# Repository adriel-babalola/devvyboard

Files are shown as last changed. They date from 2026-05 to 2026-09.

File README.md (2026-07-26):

## What is it ?
The rp2040 dev board is  a micro-controller unit that consist of the rp2040 micro processor, the 16Mbit SPI NOR Flash, a crystal oscillator that synchronizes communication in the board between the USB abd rp2040, a voltage regulator, reset and boot switch.

##  Why i built it ?
I built devvy, to understand in depth what exactly goes on in a micro-controller, and how exactly do teh components interact, and now i understand what goes on behind the scenes plus i made a rp2040 dev board.

## Assembly Instructions
1. PCB Assembly: All 0402/0603 SMD components soldered by PCBWay PCBA
2. Manual Soldering: 
   - pin Headers 
3. Testing: Apply 5V via USB-C, probe 3V3 rail with multimeter (should show 3.3V), but I tested it with an LED on the 3v3 and it works fine, will proceed to much complex projects later on.
4. Firmware: Flash using RP2040 USB bootloader (hold BOOT, press RESET, drag `.uf2` to `RPI-RP2` drive)

## CAD & Design Files
- PCB Design : KiCAD – see `devvyboard/` folder
- Gerbers: `devvyboard_gebers.zip`
- 3D CAD: `.step` files in `devvyboard_3d_step/` folder

## The Final Soldered Borad

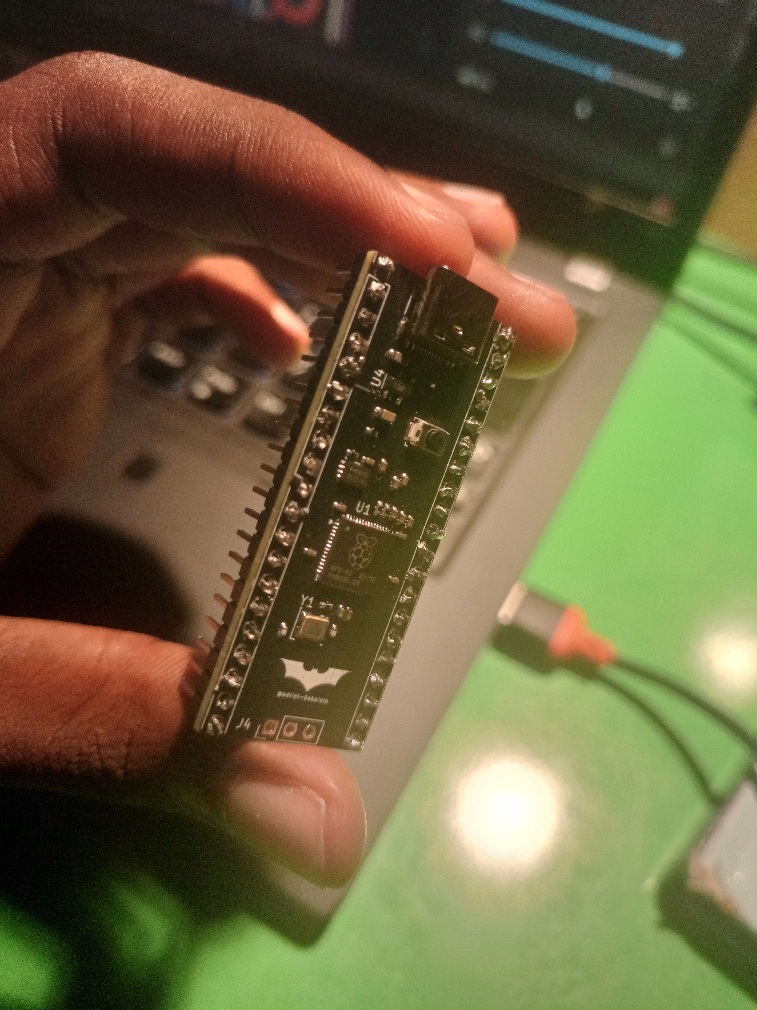
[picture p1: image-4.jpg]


## The CAD View 
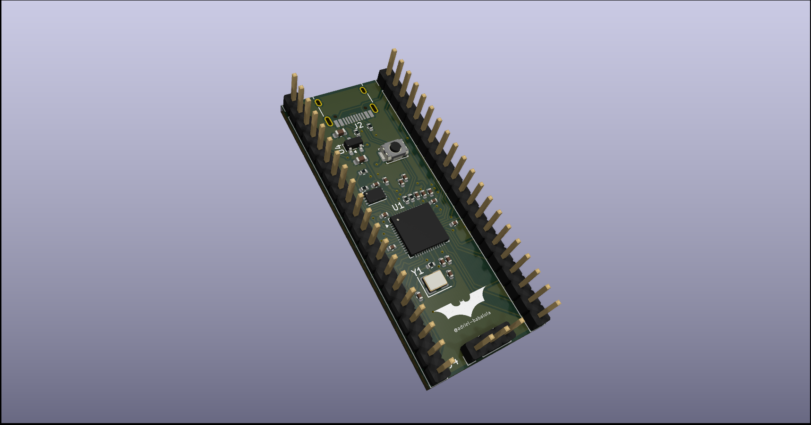
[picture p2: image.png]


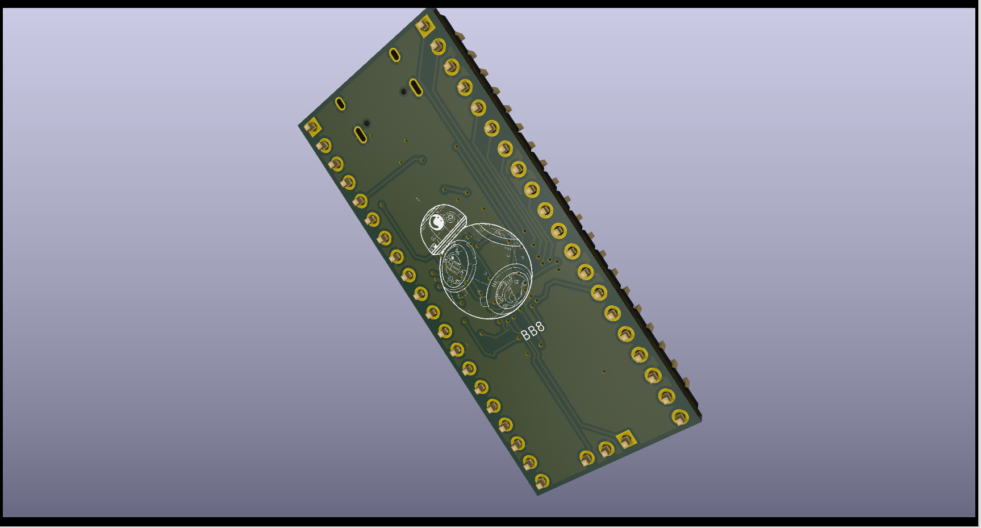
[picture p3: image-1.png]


## The Schematics 
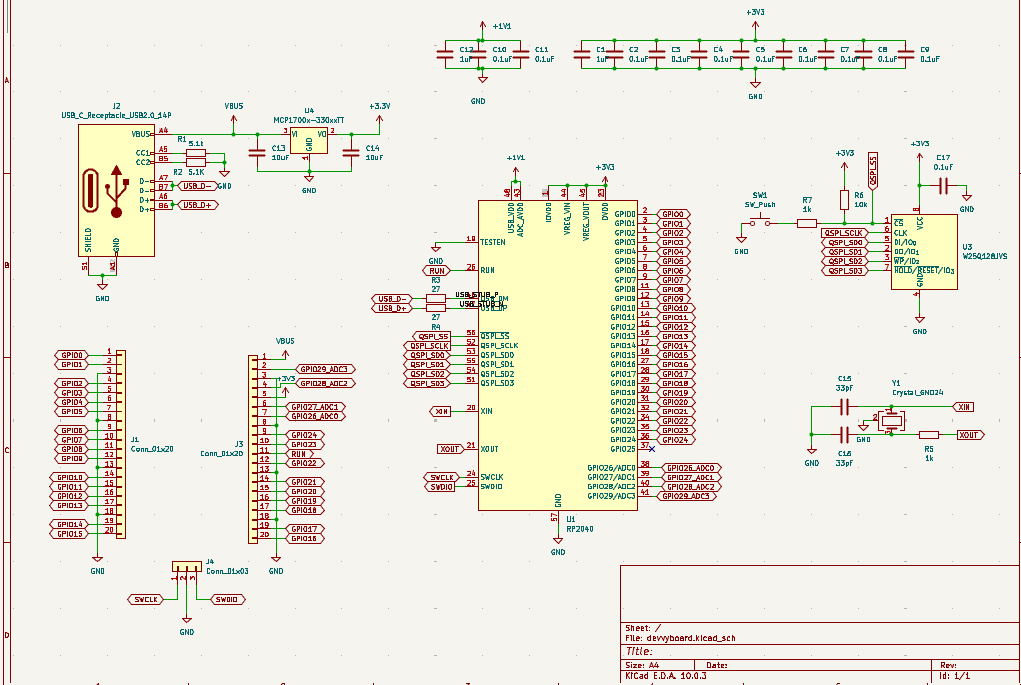
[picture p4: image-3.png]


## The Final Routed PCB
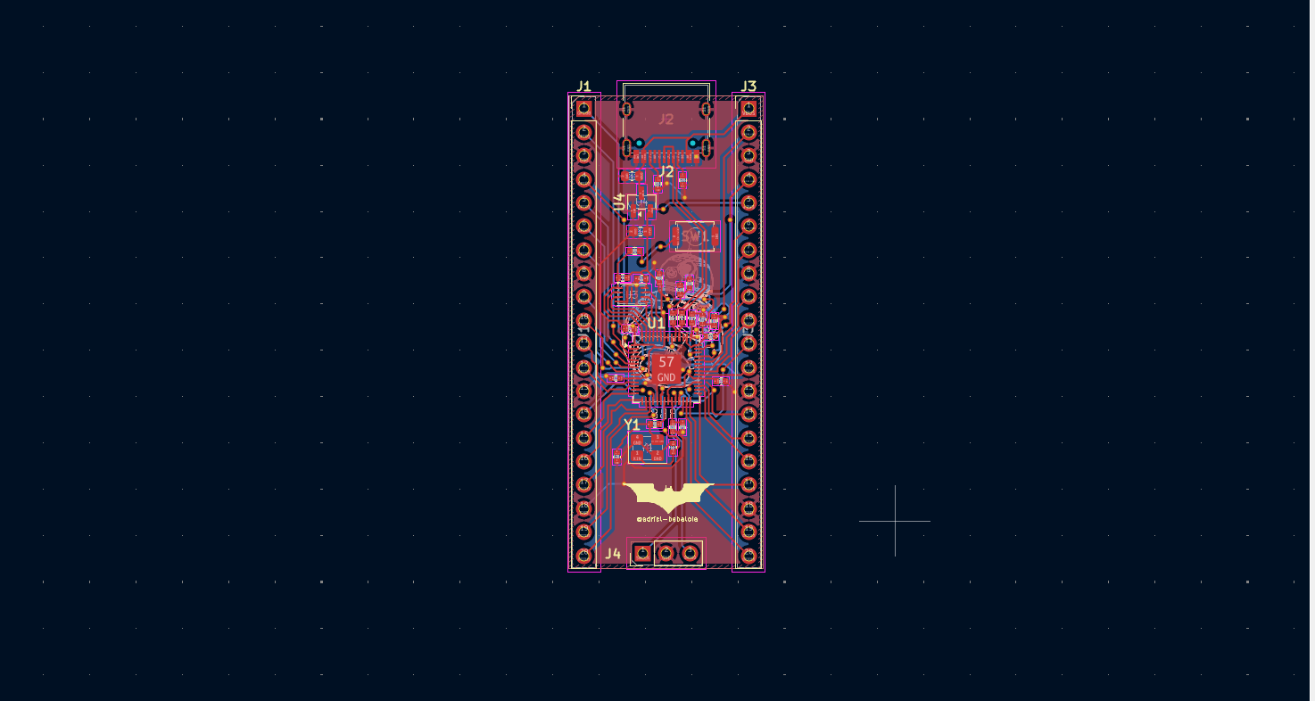
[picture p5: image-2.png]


## Bill of Materials

| Name | Purpose | Qty | Total (USD) | Link | Distributor |
|---|---|-----|---|---|---|
|Connectors | For external connections | 10 | $1.5 | [Connectors](https://www.aliexpress.com/item/1005007385580884.html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) | Aliexpress
|Soldering Iron | To Solder | 1 | $5.3 | [Soldering Iron](https://www.aliexpress.com/item/1005009943749655.html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) | Aliexpress
| RP2040 | Dual-core ARM Cortex-M0+ microcontroller — the brain of the board | 1 | $0.69 | [LCSC C2040](https://www.lcsc.com/product-detail/C2040.html) | JLCPCB |
| W25Q16JVUXIQ Flash | 16Mbit SPI NOR Flash — stores firmware and data | 1 | $0.18 | [LCSC C2843335](https://www.lcsc.com/product-detail/C2843335.html) | JLCPCB |
| 12MHz Crystal (X322512MSB4SI) | Crystal oscillator — synchronises USB and RP2040 communication | 1 | $0.04 | [LCSC C9002](https://www.lcsc.com/product-detail/C9002.html) | JLCPCB |
| TYPE-C-31-M-12 USB-C Receptacle | USB-C port — data transfer and board power input | 1 | $0.09 | [LCSC C165948](https://www.lcsc.com/product-detail/C165948.html) | JLCPCB |
| MCP1700T-3302E/TT LDO | 3.3V voltage regulator — powers all 3.3V components | 1 | $0.18 | [LCSC C39051](https://www.lcsc.com/product-detail/C39051.html) | JLCPCB |
| Alps SKRKAHE020 Tactile Switch | Reset/boot switch — resets or boot-selects the RP2040 | 1 | $0.08 | [LCSC C202388](https://www.lcsc.com/product-detail/C202388.html) | LCSC |
| 100nF 0402 Capacitor x11 | Decoupling — filters noise on power rails | 11 | $0.02 | [LCSC C1525](https://www.lcsc.com/product-detail/C1525.html) | JLCPCB |
| 1uF 0402 Capacitor x2 | Bulk decoupling — stabilises power at RP2040 and USB | 2 | $0.02 | [LCSC C52923](https://www.lcsc.com/product-detail/C52923.html) | JLCPCB |
| 10uF 0603 Capacitor x2 | Input/output bulk capacitance — LDO stability | 2 | $0.02 | [LCSC C19702](https://www.lcsc.com/product-detail/C19702.html) | JLCPCB |
| 33pF 0402 Capacitor x2 | Crystal load capacitors — correct oscillator loading | 2 | $0.01 | [LCSC C1557](https://www.lcsc.com/product-detail/C1557.html) | JLCPCB |
| 5.1k 0402 Resistor x2 | USB-C CC resistors — identifies board as USB device to host | 2 | $0.01 | [LCSC C25905](https://www.lcsc.com/product-detail/C25905.html) | JLCPCB |
| 27R 0402 Resistor x2 | USB D+/D- series resistors — USB signal integrity | 2 | $0.01 | [LCSC C352446](https://www.lcsc.com/product-detail/C352446.html) | JLCPCB |
| 1k 0402 Resistor x2 | Current limiting / pull resistors | 2 | $0.01 | [LCSC C11702](https://www.lcsc.com/product-detail/C11702.html) | JLCPCB |
| 10k 0402 Resistor | Pull-up/pull-down bias resistor | 1 | $0.01 | [LCSC C25744](https://www.lcsc.com/product-detail/C25744.html) | JLCPCB |
| PCB Fabrication (devvyboard_Y4) | 2-layer PCB — the board itself | 5 | $2.00 | — | JLCPCB |
| PCBA SMT Assembly | SMT assembly of all SMD components | 2 | $80.06 | — | JLCPCB |
| Shipping PCB | Economical Global Direct Line 14-19 business days | - | $13.10 | — | JLCPCB |
|Shipping Aliexpress | - | - | $5.23 | - | Aliexpress
| **TOTAL** | | | **$107.36** | | |

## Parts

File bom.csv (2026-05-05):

Name | Purpose | Quantity | Total (USD) | Link | Distributor
RP2040 | Dual-core ARM Cortex-M0+ microcontroller - the brain of the board | 1 | $0.69 | https://www.lcsc.com/product-detail/C2040.html | JLCPCB (C2040)
W25Q16JVUXIQ Flash | 16Mbit SPI NOR Flash - stores firmware and data | 1 | $0.18 | https://www.lcsc.com/product-detail/C2843335.html | JLCPCB (C2843335)
12MHz Crystal (X322512MSB4SI) | Crystal oscillator - synchronises USB and RP2040 communication | 1 | $0.04 | https://www.lcsc.com/product-detail/C9002.html | JLCPCB (C9002)
TYPE-C-31-M-12 USB-C Receptacle | USB-C port - data transfer and board power input | 1 | $0.09 | https://www.lcsc.com/product-detail/C165948.html | JLCPCB (C165948)
MCP1700T-3302E/TT LDO | 3.3V voltage regulator - powers all 3.3V components | 1 | $0.18 | https://www.lcsc.com/product-detail/C39051.html | JLCPCB (C39051)
Alps SKRKAHE020 Tactile Switch | Reset/boot switch - resets or boot-selects the RP2040 | 1 | $0.08 | https://www.lcsc.com/product-detail/C202388.html | LCSC (C202388)
1x20 Pin Headers (x2) | GPIO breakout - exposes all RP2040 pins for external projects | 10 | $1.50 | https://www.aliexpress.com | AliExpress
Soldering Iron | To solder the connectors and switch | 1 | $5.30 | https://www.aliexpress.com | AliExpress
100nF 0402 Capacitor (x11) | Decoupling - filters noise on power rails | 11 | $0.02 | https://www.lcsc.com/product-detail/C1525.html | JLCPCB (C1525)
1uF 0402 Capacitor (x2) | Bulk decoupling - stabilises power at RP2040 and USB | 2 | $0.02 | https://www.lcsc.com/product-detail/C52923.html | JLCPCB (C52923)
10uF 0603 Capacitor (x2) | Input/output bulk capacitance - LDO stability | 2 | $0.02 | https://www.lcsc.com/product-detail/C19702.html | JLCPCB (C19702)
33pF 0402 Capacitor (x2) | Crystal load capacitors - correct oscillator loading | 2 | $0.01 | https://www.lcsc.com/product-detail/C1557.html | JLCPCB (C1557)
5.1k 0402 Resistor (x2) | USB-C CC resistors - identifies board as USB device to host | 2 | $0.01 | https://www.lcsc.com/product-detail/C25905.html | JLCPCB (C25905)
27R 0402 Resistor (x2) | USB D+/D- series resistors - USB signal integrity | 2 | $0.01 | https://www.lcsc.com/product-detail/C352446.html | JLCPCB (C352446)
1k 0402 Resistor (x2) | Current limiting / pull resistors | 2 | $0.01 | https://www.lcsc.com/product-detail/C11702.html | JLCPCB (C11702)
10k 0402 Resistor | Pull-up/pull-down bias resistor | 1 | $0.01 | https://www.lcsc.com/product-detail/C25744.html | JLCPCB (C25744)
PCB Fabrication (devvyboard_Y4) | 2-layer PCB - the board itself | 5 | $2.00 | - | JLCPCB
PCBA Assembly | SMT assembly of all SMD components | 2 | $80.06 | - | JLCPCB
Shipping | Delivery | 1 | $18.50 | - | JLCPCB + AliExpress
TOTAL |  |  |  | $107.36

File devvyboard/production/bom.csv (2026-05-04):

Designator | Footprint | Quantity | Value | LCSC Part #
C1, C12 | 0402 | 2 | 1uF
C10, C11, C17, C2, C3, C4, C5, C6, C7, C8, C9 | 0402 | 11 | 0.1uF
C13, C14 | 0603 | 2 | 10uF
C15, C16 | 0402 | 2 | 33pF
J1, J3 | PinHeader_1x20_P2.54mm_Vertical | 2 | Conn_01x20
J2 | USB_C_Receptacle_HRO_TYPE-C-31-M-12 | 1 | USB_C_Receptacle_USB2.0_14P
J4 | PinHeader_1x03_P2.54mm_Vertical | 1 | Conn_01x03
R1, R2 | 0402 | 2 | 5.1k
R3, R4 | 0402 | 2 | 27
R5, R7 | 0402 | 2 | 1k
R6 | 0402 | 1 | 10k
SW1 | SW_Push_SPST_NO_Alps_SKRK | 1 | SW_Push
U1 | QFN-56-1EP_7x7mm_P0.4mm_EP3.2x3.2mm | 1 | RP2040
U3 | Winbond_USON-8-1EP_3x2mm_P0.5mm_EP0.2x1.6mm | 1 | W25Q16JVUXIQ
U4 | SOT-23 | 1 | MCP1700x-330xxTT
Y1 | Crystal_SMD_3225-4Pin_3.2x2.5mm | 1 | Crystal_GND24

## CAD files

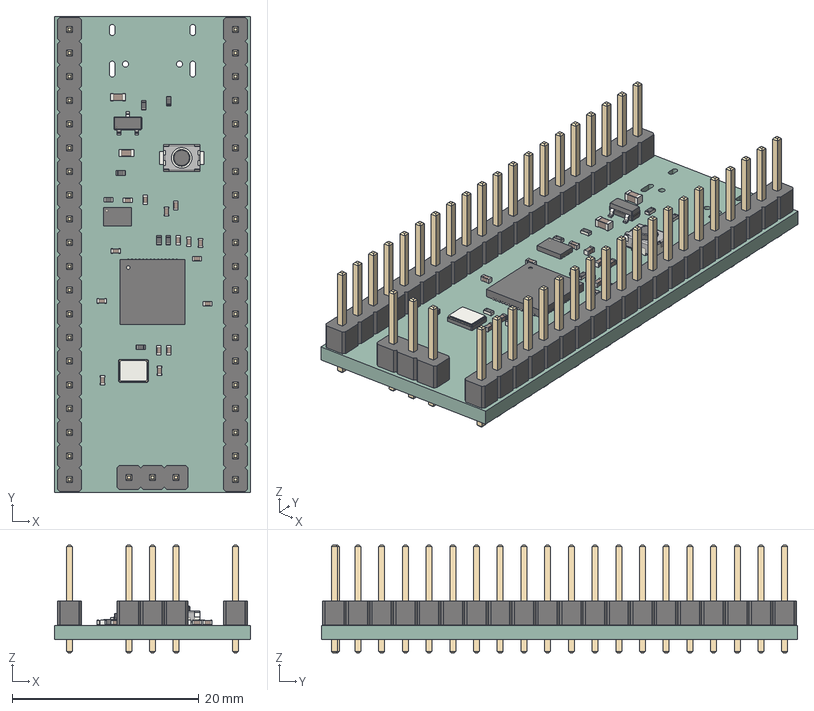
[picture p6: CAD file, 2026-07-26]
devvyboard 3d step/.step
21.0 x 51.0 x 11.5 mm
C_0402_1005Metric x 15
R_0402_1005Metric x 7
C_0603_1608Metric x 2
SOT-23
SW_Push_SPST_NO_Alps_SKRK
Crystal_SMD_3225-4Pin_3.2x2.5mm
QFN-56-1EP_7x7mm_P0.4mm_EP3.2x3.2mm
PinHeader_1x03_P254mm_Vertical
PinHeader_1x20_P254mm_Vertical x 2
Winbond_USON-8-1EP_3x2mm_P0.5mm_EP0.2x1.6mm
devvyboard_PCB

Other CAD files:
devvyboard_3d_step/devvyboard.step
devvyboard_3d_step/devvyboard.f3z

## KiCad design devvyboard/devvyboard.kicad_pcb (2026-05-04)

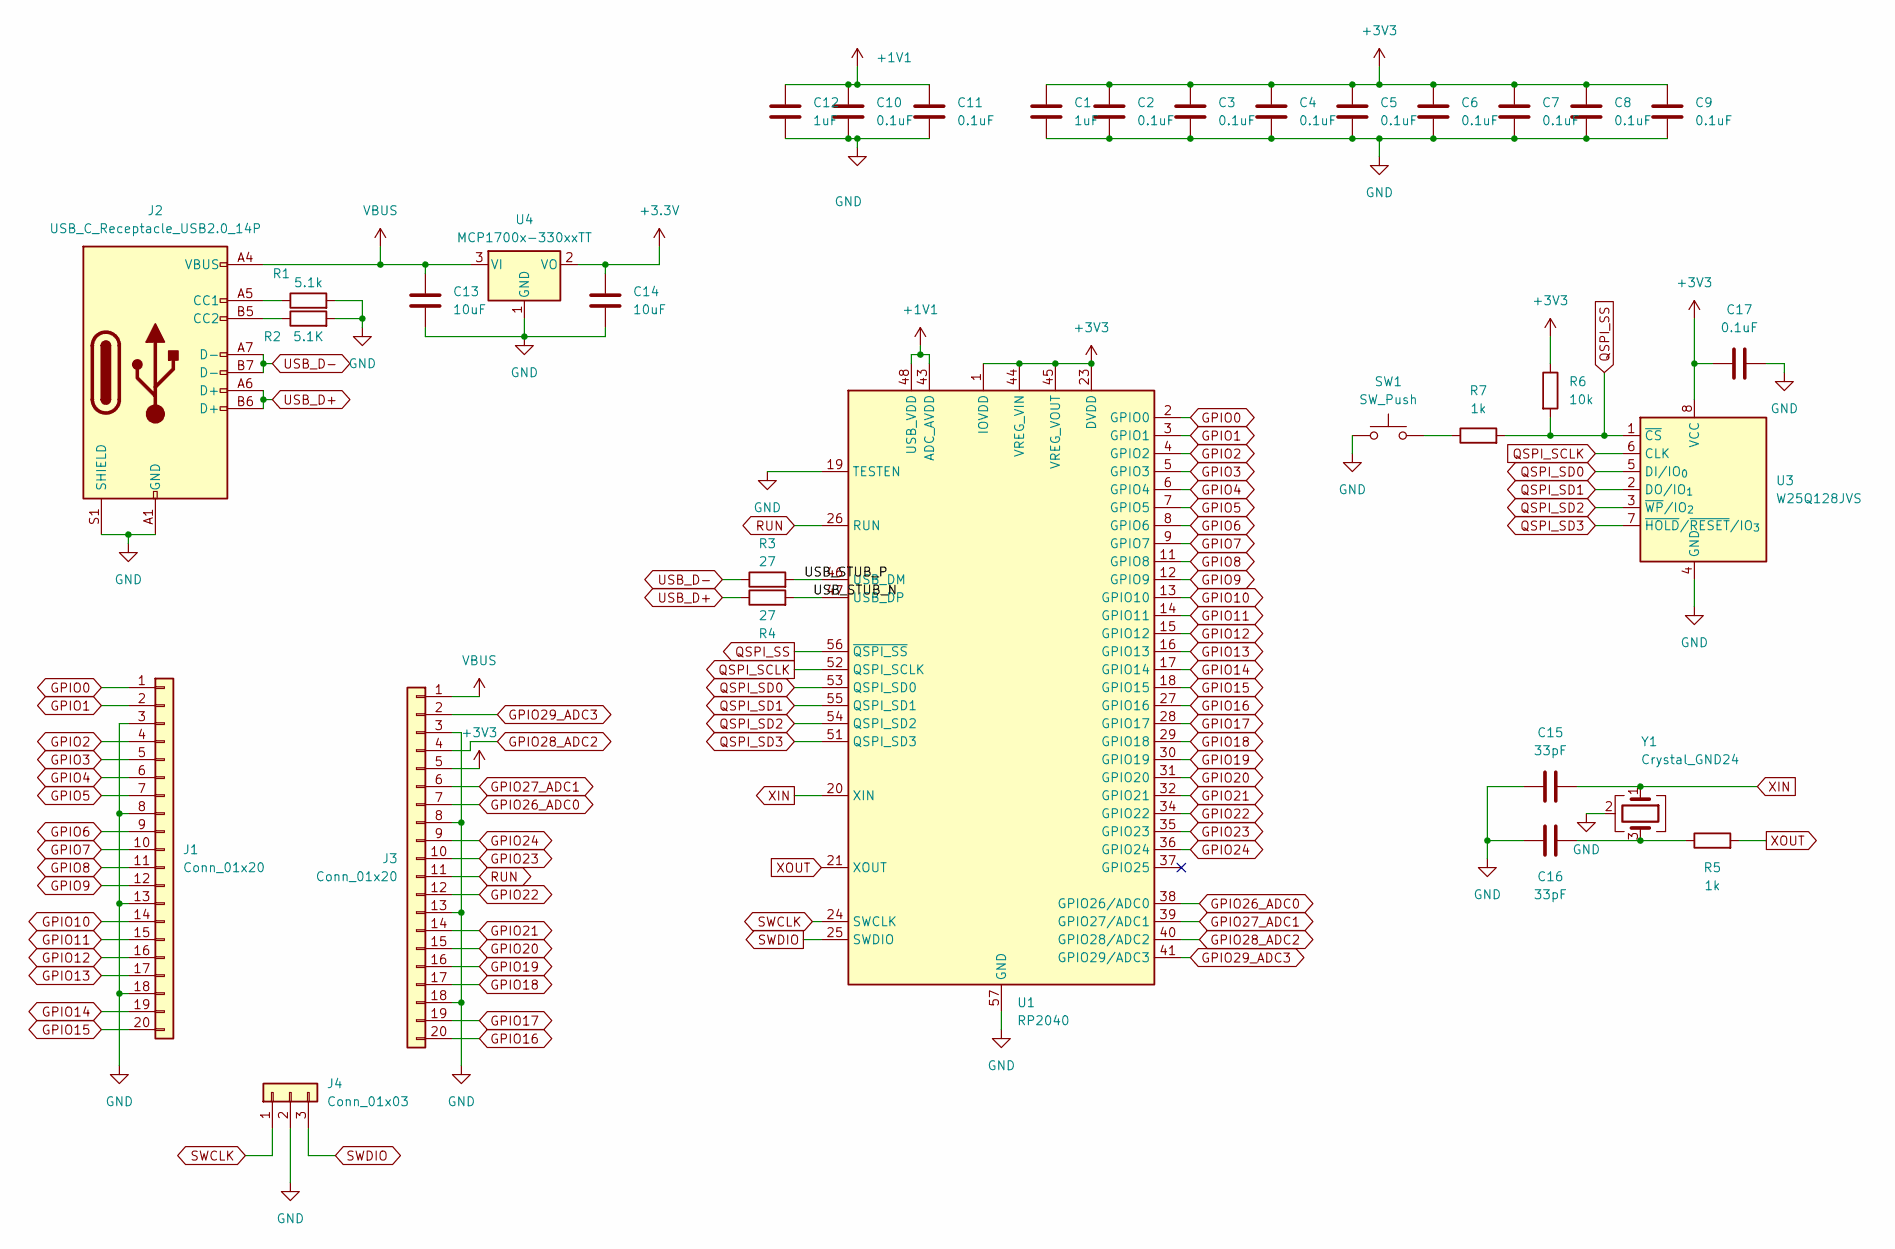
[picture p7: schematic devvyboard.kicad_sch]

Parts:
C1, C12: 1uF; C_0402_1005Metric
C2, C3, C4, C5, C6, C7, C8, C9, C10, C11, C17: 0.1uF; C_0402_1005Metric
C13, C14: 10uF; C_0603_1608Metric
C15, C16: 33pF; C_0402_1005Metric
J1, J3: Conn_01x20; PinHeader_1x20_P2.54mm_Vertical
J2: USB_C_Receptacle_USB2.0_14P; USB_C_Receptacle_HRO_TYPE-C-31-M-12
J4: Conn_01x03; PinHeader_1x03_P2.54mm_Vertical
R1: 5.1k; R_0402_1005Metric
R2: 5.1K; R_0402_1005Metric
R3, R4: 27; R_0402_1005Metric
R5, R7: 1k; R_0402_1005Metric
R6: 10k; R_0402_1005Metric
SW1: SW_Push; SW_Push_SPST_NO_Alps_SKRK
U1: RP2040; QFN-56-1EP_7x7mm_P0.4mm_EP3.2x3.2mm
U3: W25Q128JVS; Winbond_USON-8-1EP_3x2mm_P0.5mm_EP0.2x1.6mm
U4: MCP1700x-330xxTT; SOT-23
Y1: Crystal_GND24; Crystal_SMD_3225-4Pin_3.2x2.5mm

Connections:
+1V1: C10.1, C11.1, C12.1, U1.43 (ADC_AVDD), U1.48 (USB_VDD)
/USB_STUB_N: R4.2, U1.47 (USB_DP)
/USB_STUB_P: R3.2, U1.46 (USB_DM)
GND: C1.2, C2.2, C3.2, C4.2, C5.2, C6.2, C7.2, C8.2, C9.2, C10.2, C11.2, C12.2, C13.2, C14.2, C15.1, C16.1, C17.1, J1.3, J1.8, J1.13, J1.18, J2.A1 (GND), J2.A12 (GND), J2.B1 (GND), J2.B12 (GND), J2.S1 (SHIELD), J3.3, J3.8, J3.13, J3.18, J4.2, R1.2, R2.2, SW1.1, U1.19 (TESTEN), U1.57 (GND), U3.4 (GND), U4.1 (GND), Y1.2 (G), Y1.4 (G)
GPIO0: J1.1, U1.2 (GPIO0)
GPIO1: J1.2, U1.3 (GPIO1)
GPIO2: J1.4, U1.4 (GPIO2)
GPIO3: J1.5, U1.5 (GPIO3)
GPIO4: J1.6, U1.6 (GPIO4)
GPIO5: J1.7, U1.7 (GPIO5)
GPIO6: J1.9, U1.8 (GPIO6)
GPIO7: J1.10, U1.9 (GPIO7)
GPIO8: J1.11, U1.11 (GPIO8)
GPIO9: J1.12, U1.12 (GPIO9)
GPIO10: J1.14, U1.13 (GPIO10)
GPIO11: J1.15, U1.14 (GPIO11)
GPIO12: J1.16, U1.15 (GPIO12)
GPIO13: J1.17, U1.16 (GPIO13)
GPIO14: J1.19, U1.17 (GPIO14)
GPIO15: J1.20, U1.18 (GPIO15)
GPIO16: J3.20, U1.27 (GPIO16)
GPIO17: J3.19, U1.28 (GPIO17)
GPIO18: J3.17, U1.29 (GPIO18)
GPIO19: J3.16, U1.30 (GPIO19)
GPIO20: J3.15, U1.31 (GPIO20)
GPIO21: J3.14, U1.32 (GPIO21)
GPIO22: J3.12, U1.34 (GPIO22)
GPIO23: J3.10, U1.35 (GPIO23)
GPIO24: J3.9, U1.36 (GPIO24)
GPIO26_ADC0: J3.7, U1.38 (GPIO26/ADC0)
GPIO27_ADC1: J3.6, U1.39 (GPIO27/ADC1)
GPIO28_ADC2: J3.4, U1.40 (GPIO28/ADC2)
GPIO29_ADC3: J3.2, U1.41 (GPIO29/ADC3)
unnamed: C16.2, R5.1, Y1.3
unnamed: J2.A5 (CC1), R1.1
unnamed: J2.B5 (CC2), R2.1
unnamed: R7.1, SW1.2
QSPI_SCLK: U1.52 (QSPI_SCLK), U3.6 (CLK)
QSPI_SD0: U1.53 (QSPI_SD0), U3.5 (DI/IO_{0})
QSPI_SD1: U1.55 (QSPI_SD1), U3.2 (DO/IO_{1})
QSPI_SD2: U1.54 (QSPI_SD2), U3.3 (~WP/IO_{2})
QSPI_SD3: U1.51 (QSPI_SD3), U3.7 (~HOLD/~RESET/IO_{3})
QSPI_SS: R6.2, R7.2, U1.56 (~QSPI_SS), U3.1 (~CS)
RUN: J3.11, U1.26 (RUN)
SWCLK: J4.1, U1.24 (SWCLK)
SWDIO: J4.3, U1.25 (SWDIO)
USB_D+: J2.A6 (D+), J2.B6 (D+), R4.1
USB_D-: J2.A7 (D-), J2.B7 (D-), R3.1
VBUS: C13.1, J2.A4 (VBUS), J2.A9 (VBUS), J2.B4 (VBUS), J2.B9 (VBUS), J3.1, U4.3 (VI)
XIN: C15.2, U1.20 (XIN), Y1.1
XOUT: R5.2, U1.21 (XOUT)

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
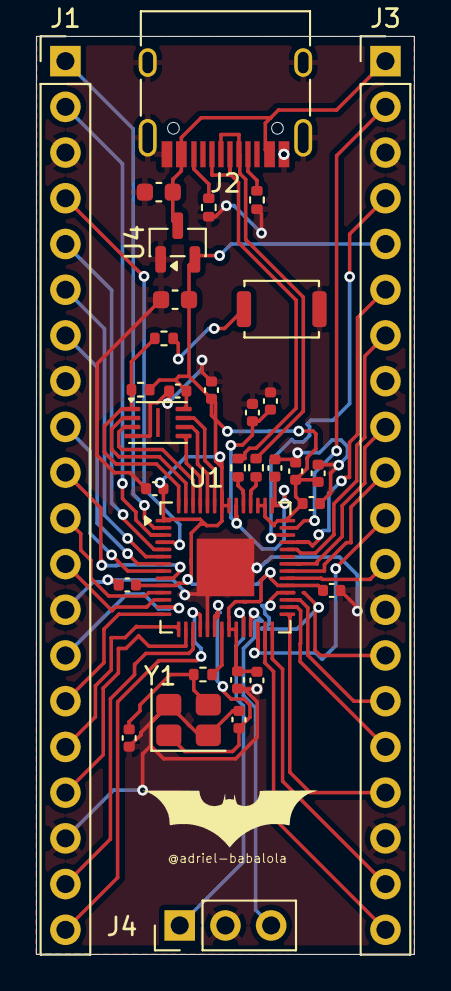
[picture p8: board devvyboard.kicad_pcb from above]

Board: 2 copper layers, 21.0 x 51.0 mm, 33 parts (0 on the bottom side), 52 nets.

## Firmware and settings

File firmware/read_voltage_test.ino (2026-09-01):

int readPin = A1;
int readVal;
float V2 =  0;
int ourDelay = 500;

void setup() {
  // put your setup code here, to run once:
  pinMode(readPin, INPUT);
  Serial.begin(9600);
}

void loop() {
  // put your main code here, to run repeatedly:
  readVal = analogRead(readPin);
  V2 = (5./1023.)* readVal;
  Serial.println(V2);
  delay(ourDelay);

}

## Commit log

2026-05-05 proper readme and structure
    [bom.csv, devvyboard.step]
2026-07-26 moved gebbers and made another .step
    [.step]
2026-07-26 renamed a folder and upadted readme
    [.step, devvyboard.step]
2026-07-26 converted my .step to f3z
    [devvyboard.f3z]
